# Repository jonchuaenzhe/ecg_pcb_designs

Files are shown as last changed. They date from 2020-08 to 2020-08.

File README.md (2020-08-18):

# EG3301R: Custom ECG Printed Circuit Board Designs

This repo contains the EAGLE files for the PCB design of a prototype double-lead ECG filter and amplifier as well as the final product: a compact 12-lead ECG filter and amplifier that has maximum dimensions of 70mm by 50mm. The pins S0 and S1 control the multiplexer that switches the input signal to the ECG monitor such that a ECG which comprises of 3 rows of 4 leads (plus 1 row of Lead 2) can be generated.

Picture of a Standard ECG

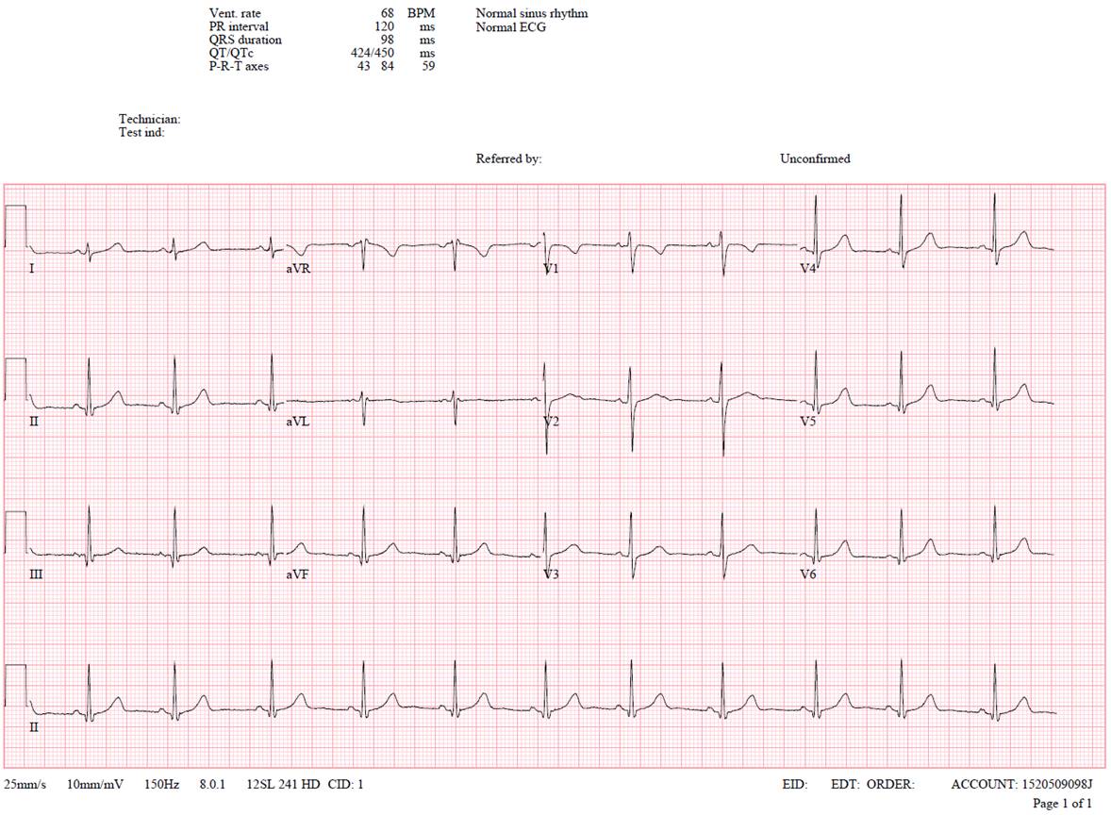
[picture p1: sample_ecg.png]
Picture of a Standard ECG


Board Design For 2-Lead ECG

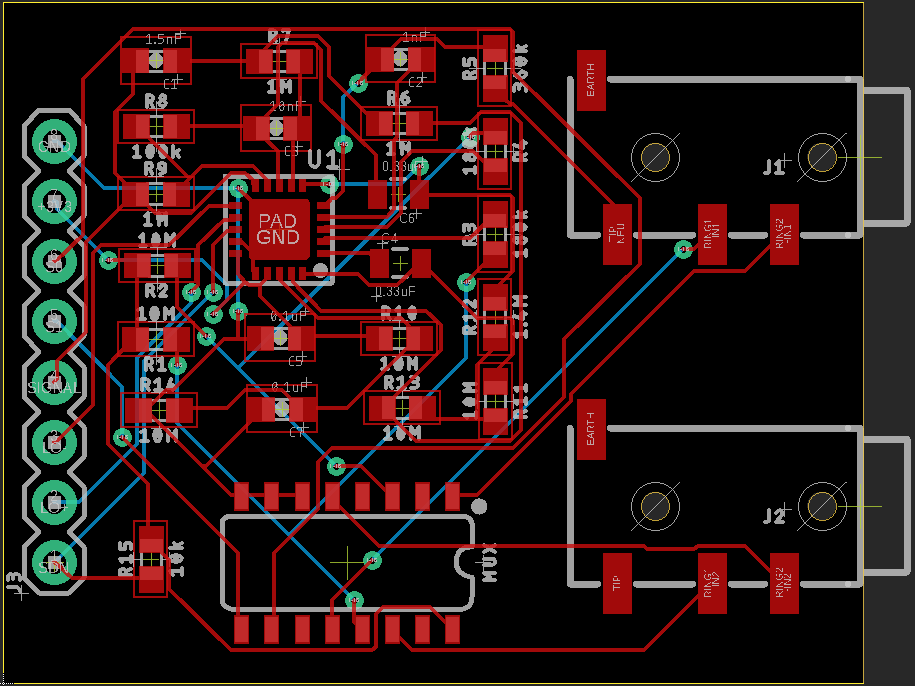
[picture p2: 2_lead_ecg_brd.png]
Board Design For 2-Lead ECG


Board Design For 12-Lead ECG

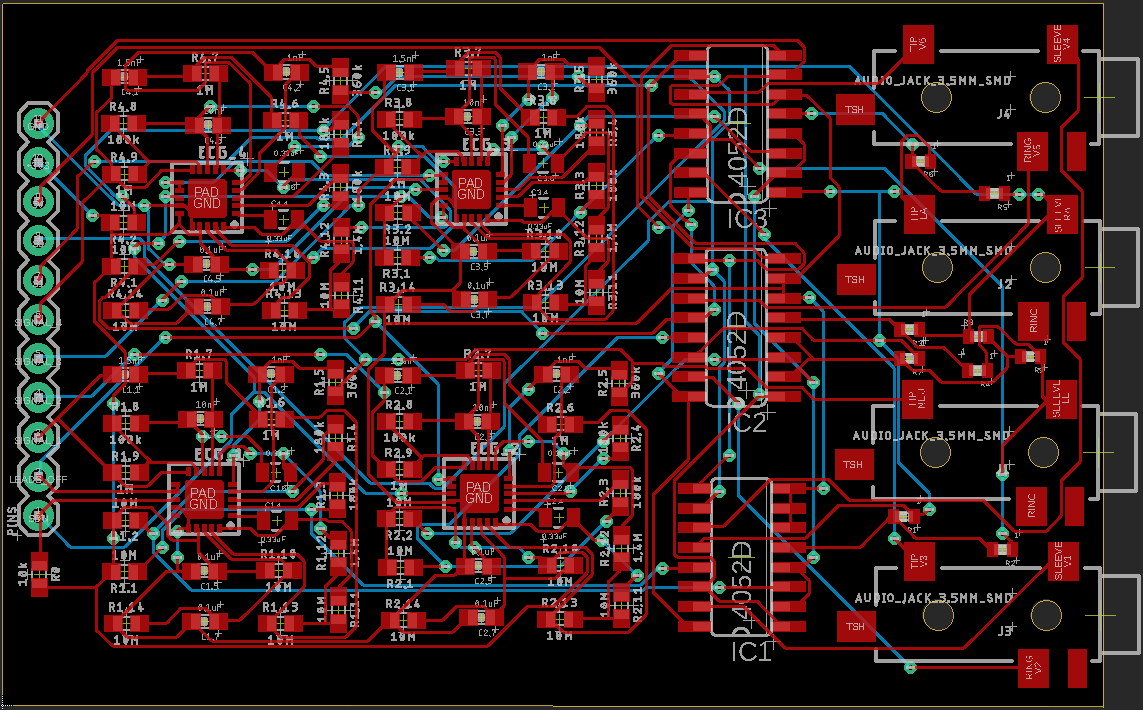
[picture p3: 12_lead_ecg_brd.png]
Board Design For 12-Lead ECG


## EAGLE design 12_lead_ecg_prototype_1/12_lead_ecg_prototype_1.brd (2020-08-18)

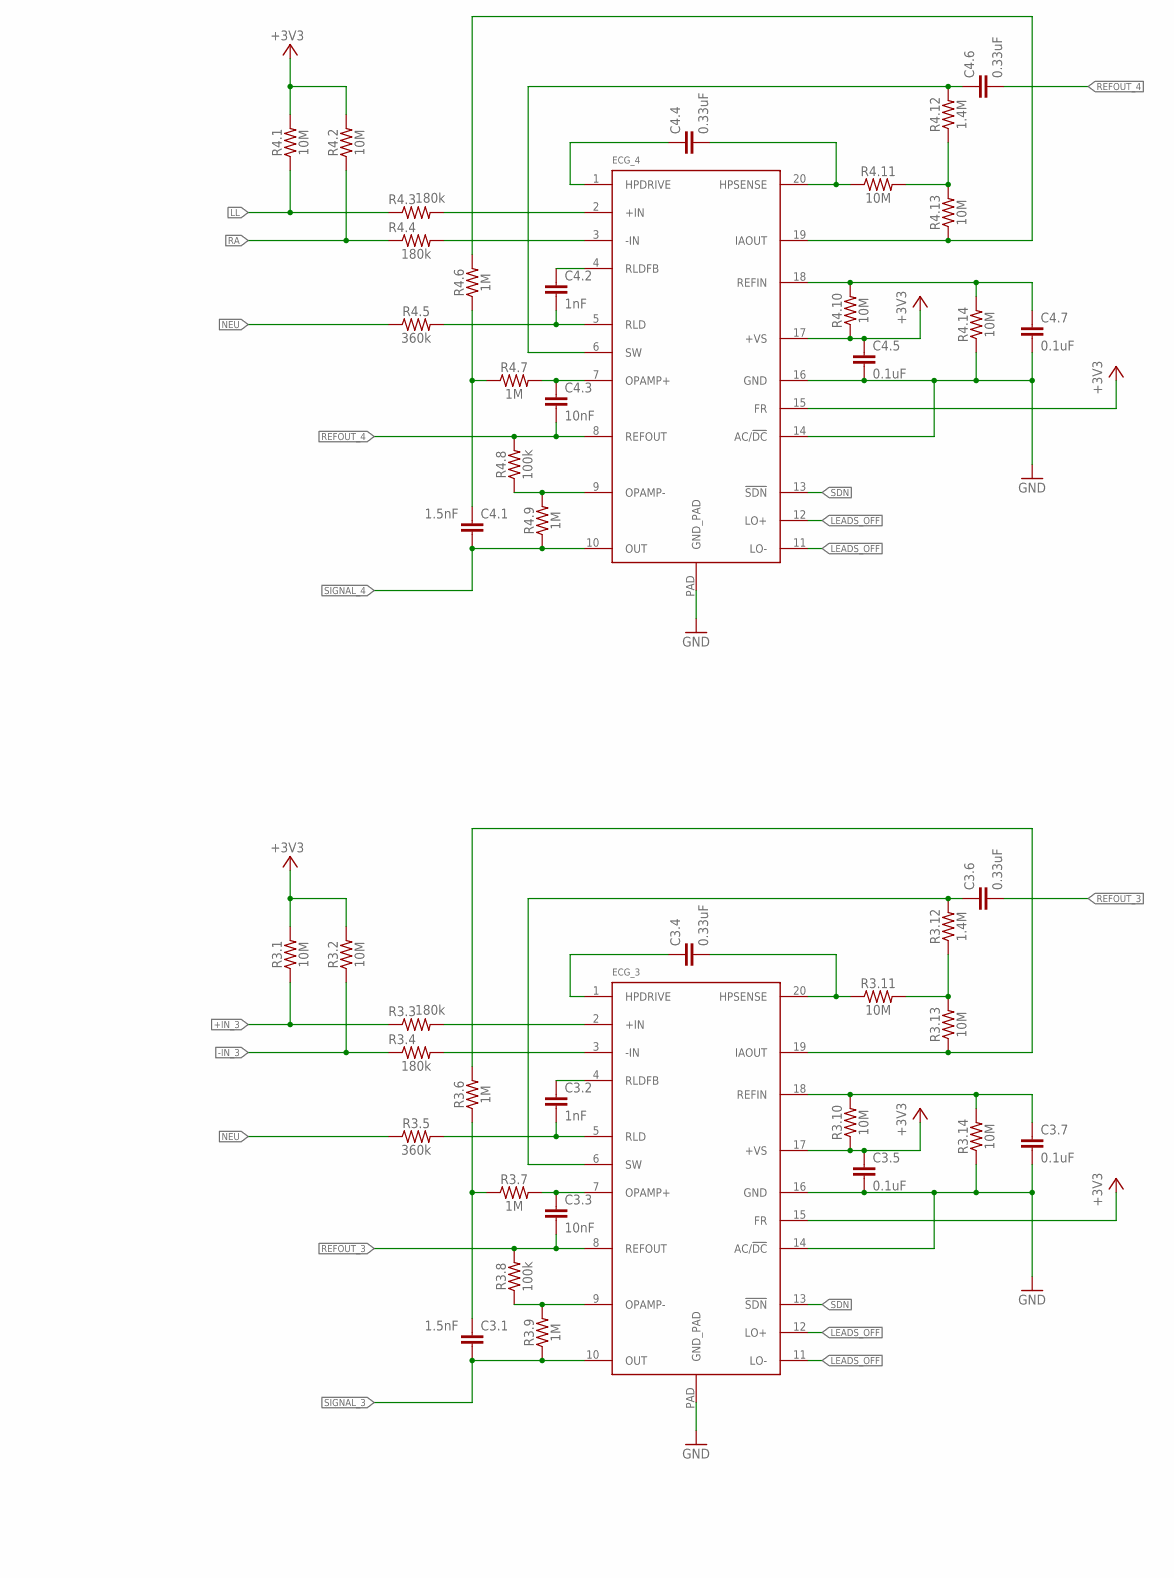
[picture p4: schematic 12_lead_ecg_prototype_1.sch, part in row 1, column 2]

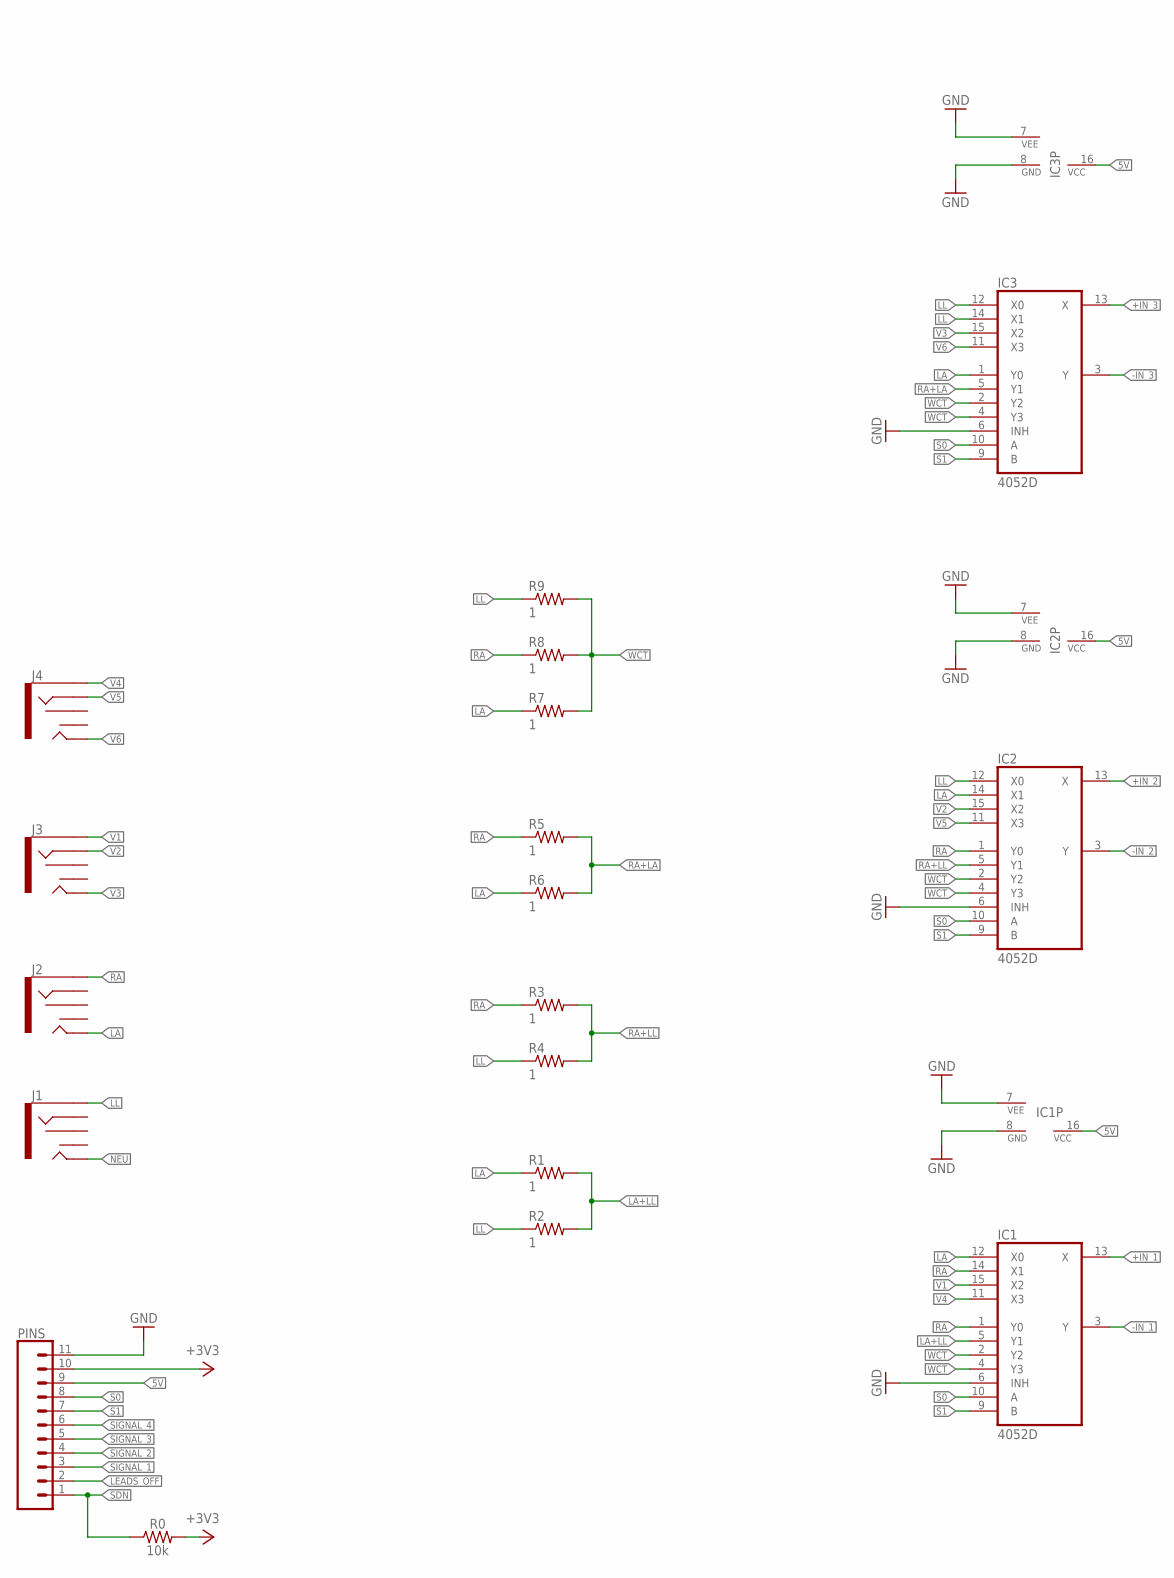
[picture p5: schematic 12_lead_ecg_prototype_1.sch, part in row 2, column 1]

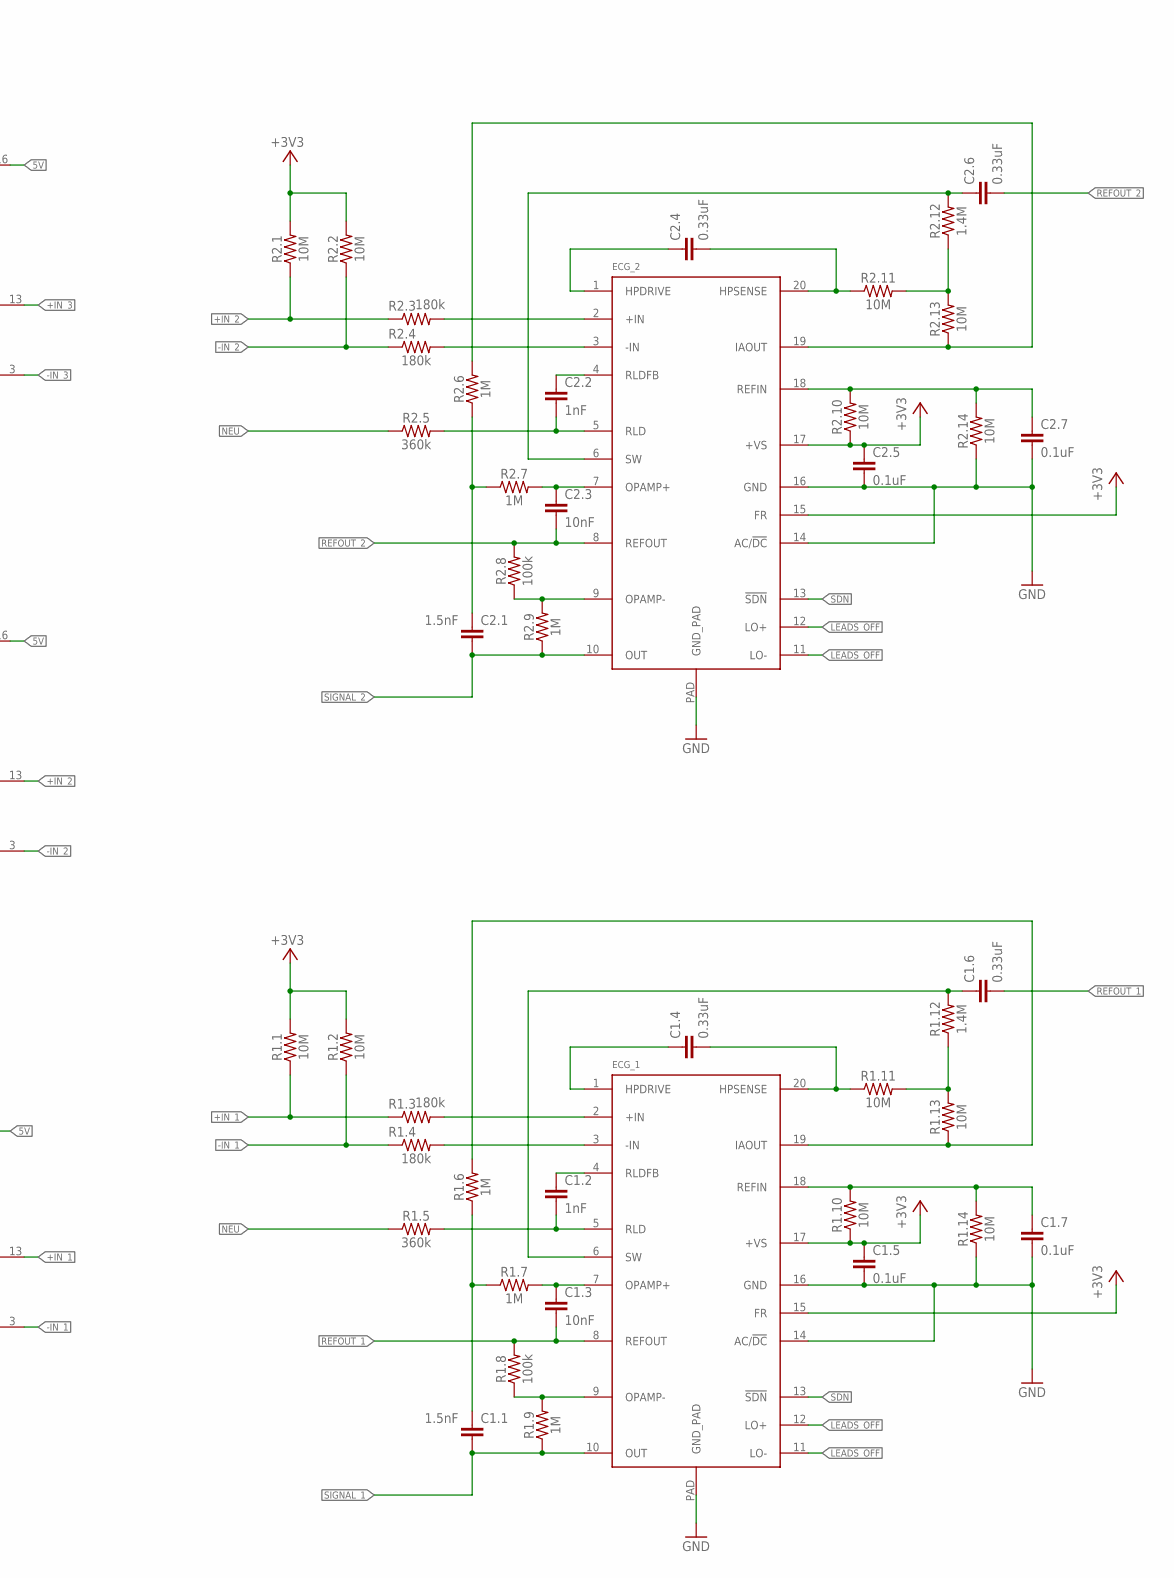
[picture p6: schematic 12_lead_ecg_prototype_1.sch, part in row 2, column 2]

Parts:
C1.1, C2.1, C3.1, C4.1: 1.5nF; 0603-CAP
C1.2, C2.2, C3.2, C4.2: 1nF; 0603-CAP
C1.3, C2.3, C3.3, C4.3: 10nF; 0603-CAP
C1.4, C1.6, C2.4, C2.6, C3.4, C3.6, C4.4, C4.6: 0.33uF; 0805
C1.5, C1.7, C2.5, C2.7, C3.5, C3.7, C4.5, C4.7: 0.1uF; 0603-CAP
ECG_1, ECG_2, ECG_3, ECG_4: AD8232ACPZ-R7; LFCSP_20
IC1, IC2, IC3: 4052D; SO16
J1, J2, J3, J4: AUDIO_JACK_3.5MM_SMD; AUDIO-JACK-3.5MM-SMD
PINS: CONN_11; 1X11
R0: 10k; 0603
R1, R2, R3, R4, R5, R6, R7, R8, R9: 1; 0402-RES
R1.1, R1.2, R1.10, R1.11, R1.13, R1.14, R2.1, R2.2, R2.10, R2.11, R2.13, R2.14, R3.1, R3.2, R3.10, R3.11, R3.13, R3.14, R4.1, R4.2, R4.10, R4.11, R4.13, R4.14: 10M; 0603
R1.3, R1.4, R2.3, R2.4, R3.3, R3.4, R4.3, R4.4: 180k; 0603
R1.5, R2.5, R3.5, R4.5: 360k; 0603
R1.6, R1.7, R1.9, R2.6, R2.7, R2.9, R3.6, R3.7, R3.9, R4.6, R4.7, R4.9: 1M; 0603
R1.8, R2.8, R3.8, R4.8: 100k; 0603
R1.12, R2.12, R3.12, R4.12: 1.4M; 0603

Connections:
5V: IC1.16 (VCC), IC2.16 (VCC), IC3.16 (VCC), PINS.9
+3V3: C1.5.1, C2.5.1, C3.5.1, C4.5.1, ECG_1.15 (FR), ECG_1.17 (+VS), ECG_2.15 (FR), ECG_2.17 (+VS), ECG_3.15 (FR), ECG_3.17 (+VS), ECG_4.15 (FR), ECG_4.17 (+VS), PINS.10, R0.2, R1.1.2, R1.2.2, R1.10.1, R2.1.2, R2.2.2, R2.10.1, R3.1.2, R3.2.2, R3.10.1, R4.1.2, R4.2.2, R4.10.1
+IN_1: IC1.13 (X), R1.1.1, R1.3.1
+IN_2: IC2.13 (X), R2.1.1, R2.3.1
+IN_3: IC3.13 (X), R3.1.1, R3.3.1
-IN_1: IC1.3 (Y), R1.2.1, R1.4.1
-IN_2: IC2.3 (Y), R2.2.1, R2.4.1
-IN_3: IC3.3 (Y), R3.2.1, R3.4.1
GND: C1.5.2, C1.7.2, C2.5.2, C2.7.2, C3.5.2, C3.7.2, C4.5.2, C4.7.2, ECG_1.14 (AC/!DC), ECG_1.16 (GND), ECG_1.PAD (GND_PAD), ECG_2.14 (AC/!DC), ECG_2.16 (GND), ECG_2.PAD (GND_PAD), ECG_3.14 (AC/!DC), ECG_3.16 (GND), ECG_3.PAD (GND_PAD), ECG_4.14 (AC/!DC), ECG_4.16 (GND), ECG_4.PAD (GND_PAD), IC1.6 (INH), IC1.7 (VEE), IC1.8 (GND), IC2.6 (INH), IC2.7 (VEE), IC3.6 (INH), IC3.7 (VEE), PINS.11, R1.14.1, R2.14.1, R3.14.1, R4.14.1
LA: IC1.12 (X0), IC2.14 (X1), IC3.1 (Y0), J2.TIP, R1.1, R6.1, R7.1
LA+LL: IC1.5 (Y1), R1.2, R2.2
LEADS_OFF: ECG_1.11 (LO-), ECG_1.12 (LO+), ECG_2.11 (LO-), ECG_2.12 (LO+), ECG_3.11 (LO-), ECG_3.12 (LO+), ECG_4.11 (LO-), ECG_4.12 (LO+), PINS.2
LL: IC2.12 (X0), IC3.12 (X0), IC3.14 (X1), J1.SLEEVE, R2.1, R4.1, R4.1.1, R4.3.1, R9.1
unnamed: ECG_1.9 (OPAMP-), R1.8.1, R1.9.2
unnamed: ECG_2.2 (+IN), R2.3.2
unnamed: ECG_1.2 (+IN), R1.3.2
unnamed: ECG_1.3 (-IN), R1.4.2
unnamed: ECG_2.3 (-IN), R2.4.2
unnamed: C1.1.1, R1.6.1, R1.7.1
unnamed: C1.3.1, ECG_1.7 (OPAMP+), R1.7.2
unnamed: C1.2.1, ECG_1.4 (RLDFB)
unnamed: C1.2.2, ECG_1.5 (RLD), R1.5.2
unnamed: ECG_1.19 (IAOUT), R1.6.2, R1.13.1
unnamed: C1.6.1, ECG_1.6 (SW), R1.12.2
unnamed: C1.7.1, ECG_1.18 (REFIN), R1.10.2, R1.14.2
unnamed: R1.11.2, R1.12.1, R1.13.2
unnamed: C1.4.2, ECG_1.20 (HPSENSE), R1.11.1
unnamed: C1.4.1, ECG_1.1 (HPDRIVE)
unnamed: C2.2.1, ECG_2.4 (RLDFB)
unnamed: C2.2.2, ECG_2.5 (RLD), R2.5.2
unnamed: IC2.8 (GND), IC3.8 (GND)
unnamed: C2.1.1, R2.6.1, R2.7.1
unnamed: C2.3.1, ECG_2.7 (OPAMP+), R2.7.2
unnamed: ECG_2.9 (OPAMP-), R2.8.1, R2.9.2
unnamed: ECG_2.19 (IAOUT), R2.6.2, R2.13.1
unnamed: C2.6.1, ECG_2.6 (SW), R2.12.2
unnamed: R2.11.2, R2.12.1, R2.13.2
unnamed: C2.4.2, ECG_2.20 (HPSENSE), R2.11.1
unnamed: C2.4.1, ECG_2.1 (HPDRIVE)
unnamed: C2.7.1, ECG_2.18 (REFIN), R2.10.2, R2.14.2
unnamed: ECG_3.2 (+IN), R3.3.2
unnamed: ECG_3.3 (-IN), R3.4.2
unnamed: C3.2.1, ECG_3.4 (RLDFB)
unnamed: C3.2.2, ECG_3.5 (RLD), R3.5.2
unnamed: C3.1.1, R3.6.1, R3.7.1
unnamed: C3.3.1, ECG_3.7 (OPAMP+), R3.7.2
unnamed: ECG_3.9 (OPAMP-), R3.8.1, R3.9.2
unnamed: ECG_3.19 (IAOUT), R3.6.2, R3.13.1
unnamed: C3.6.1, ECG_3.6 (SW), R3.12.2
unnamed: R3.11.2, R3.12.1, R3.13.2
unnamed: C3.4.2, ECG_3.20 (HPSENSE), R3.11.1
unnamed: C3.4.1, ECG_3.1 (HPDRIVE)
unnamed: C3.7.1, ECG_3.18 (REFIN), R3.10.2, R3.14.2
unnamed: ECG_4.2 (+IN), R4.3.2
unnamed: ECG_4.3 (-IN), R4.4.2
unnamed: C4.2.1, ECG_4.4 (RLDFB)
unnamed: C4.2.2, ECG_4.5 (RLD), R4.5.2
unnamed: C4.1.1, R4.6.1, R4.7.1
unnamed: C4.3.1, ECG_4.7 (OPAMP+), R4.7.2
unnamed: ECG_4.9 (OPAMP-), R4.8.1, R4.9.2
unnamed: ECG_4.19 (IAOUT), R4.6.2, R4.13.1
unnamed: C4.6.1, ECG_4.6 (SW), R4.12.2
unnamed: R4.11.2, R4.12.1, R4.13.2
unnamed: C4.4.2, ECG_4.20 (HPSENSE), R4.11.1
unnamed: C4.4.1, ECG_4.1 (HPDRIVE)
unnamed: C4.7.1, ECG_4.18 (REFIN), R4.10.2, R4.14.2
NEU: J1.TIP, R1.5.1, R2.5.1, R3.5.1, R4.5.1
RA: IC1.1 (Y0), IC1.14 (X1), IC2.1 (Y0), J2.SLEEVE, R3.1, R4.2.1, R4.4.1, R5.1, R8.1
RA+LA: IC3.5 (Y1), R5.2, R6.2
RA+LL: IC2.5 (Y1), R3.2, R4.2
REFOUT_1: C1.3.2, C1.6.2, ECG_1.8 (REFOUT), R1.8.2
REFOUT_2: C2.3.2, C2.6.2, ECG_2.8 (REFOUT), R2.8.2
REFOUT_3: C3.3.2, C3.6.2, ECG_3.8 (REFOUT), R3.8.2
REFOUT_4: C4.3.2, C4.6.2, ECG_4.8 (REFOUT), R4.8.2
S0: IC1.10 (A), IC2.10 (A), IC3.10 (A), PINS.8
S1: IC1.9 (B), IC2.9 (B), IC3.9 (B), PINS.7
SDN: ECG_1.13 (!SDN), ECG_2.13 (!SDN), ECG_3.13 (!SDN), ECG_4.13 (!SDN), PINS.1, R0.1
SIGNAL_1: C1.1.2, ECG_1.10 (OUT), PINS.3, R1.9.1
SIGNAL_2: C2.1.2, ECG_2.10 (OUT), PINS.4, R2.9.1
SIGNAL_3: C3.1.2, ECG_3.10 (OUT), PINS.5, R3.9.1
SIGNAL_4: C4.1.2, ECG_4.10 (OUT), PINS.6, R4.9.1
V1: IC1.15 (X2), J3.SLEEVE
V2: IC2.15 (X2), J3.RING
V3: IC3.15 (X2), J3.TIP
V4: IC1.11 (X3), J4.SLEEVE
V5: IC2.11 (X3), J4.RING
V6: IC3.11 (X3), J4.TIP
WCT: IC1.2 (Y2), IC1.4 (Y3), IC2.2 (Y2), IC2.4 (Y3), IC3.2 (Y2), IC3.4 (Y3), R7.2, R8.2, R9.2

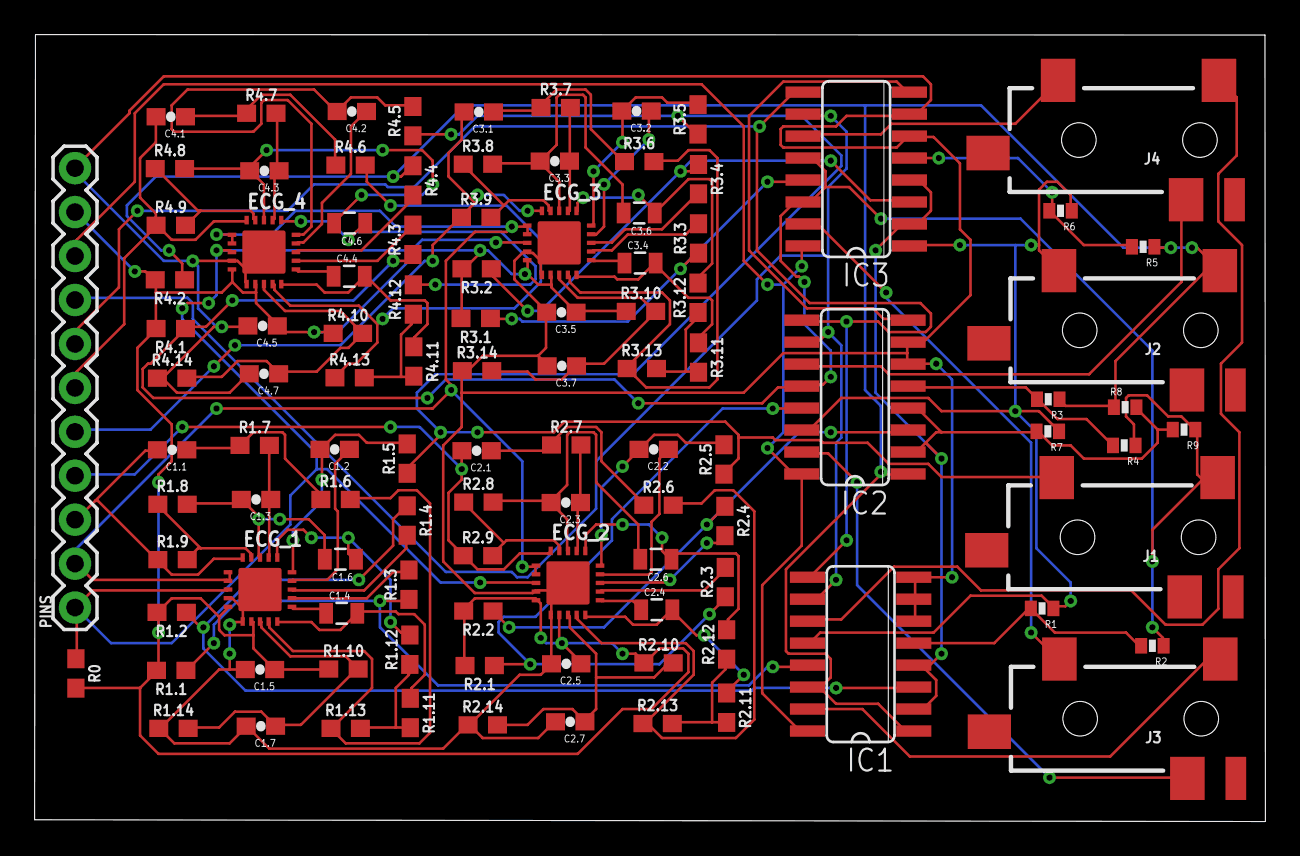
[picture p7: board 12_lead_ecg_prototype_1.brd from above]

Board: 2 copper layers, 71.2 x 45.5 mm, 106 parts (0 on the bottom side), 88 nets.

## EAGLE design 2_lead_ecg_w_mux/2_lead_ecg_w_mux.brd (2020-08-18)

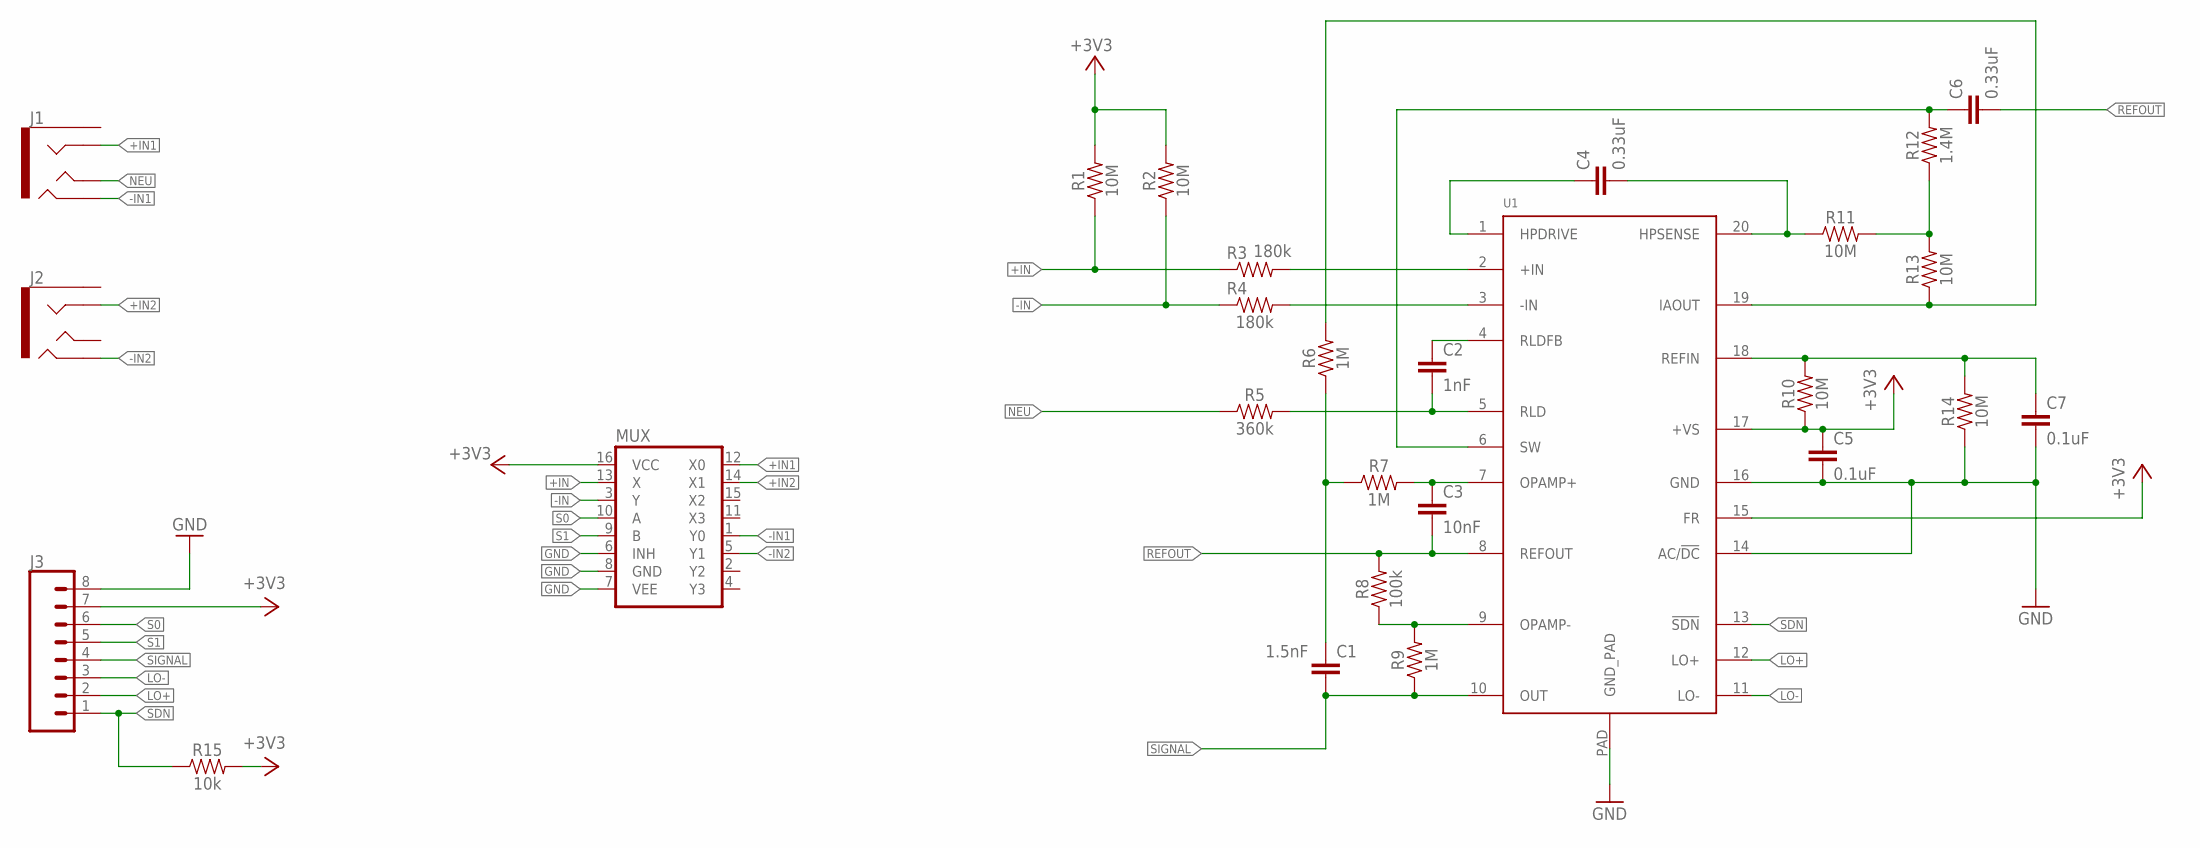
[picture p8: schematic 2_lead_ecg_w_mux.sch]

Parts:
C1: 1.5nF; 0603-CAP
C2: 1nF; 0603-CAP
C3: 10nF; 0603-CAP
C4, C6: 0.33uF; 0805
C5, C7: 0.1uF; 0603-CAP
J1, J2: AUDIO_JACK_TRRSSMD_RA; AUDIO_JACK_3.5MM_TRRS_SMD_RA
J3: CONN_08"; 1X08
MUX: 74HC4052D; SO16
R1, R2, R10, R11, R13, R14: 10M; 0603
R3, R4: 180k; 0603
R5: 360k; 0603
R6, R7, R9: 1M; 0603
R8: 100k; 0603
R12: 1.4M; 0603
R15: 10k; 0603
U1: AD8232ACPZ-R7; LFCSP_20

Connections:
+3V3: C5.1, J3.7, MUX.16 (VCC), R1.2, R2.2, R10.1, R15.2, U1.15 (FR), U1.17 (+VS)
+IN: MUX.13 (X), R1.1, R3.1
+IN1: J1.RING1, MUX.12 (X0)
+IN2: J2.RING1, MUX.14 (X1)
-IN: MUX.3 (Y), R2.1, R4.1
-IN1: J1.RING2, MUX.1 (Y0)
-IN2: J2.RING2, MUX.5 (Y1)
GND: C5.2, C7.2, J3.8, MUX.6 (INH), MUX.7 (VEE), MUX.8 (GND), R14.1, U1.14 (AC/!DC), U1.16 (GND), U1.PAD (GND_PAD)
LO+: J3.2, U1.12 (LO+)
LO-: J3.3, U1.11 (LO-)
unnamed: R8.1, R9.2, U1.9 (OPAMP-)
unnamed: R3.2, U1.2 (+IN)
unnamed: R4.2, U1.3 (-IN)
unnamed: C1.1, R6.1, R7.1
unnamed: C3.1, R7.2, U1.7 (OPAMP+)
unnamed: C2.1, U1.4 (RLDFB)
unnamed: C2.2, R5.2, U1.5 (RLD)
unnamed: R6.2, R13.1, U1.19 (IAOUT)
unnamed: C6.1, R12.2, U1.6 (SW)
unnamed: C7.1, R10.2, R14.2, U1.18 (REFIN)
unnamed: R11.2, R12.1, R13.2
unnamed: C4.2, R11.1, U1.20 (HPSENSE)
unnamed: C4.1, U1.1 (HPDRIVE)
NEU: J1.TIP, R5.1
REFOUT: C3.2, C6.2, R8.2, U1.8 (REFOUT)
S0: J3.6, MUX.10 (A)
S1: J3.5, MUX.9 (B)
SDN: J3.1, R15.1, U1.13 (!SDN)
SIGNAL: C1.2, J3.4, R9.1, U1.10 (OUT)

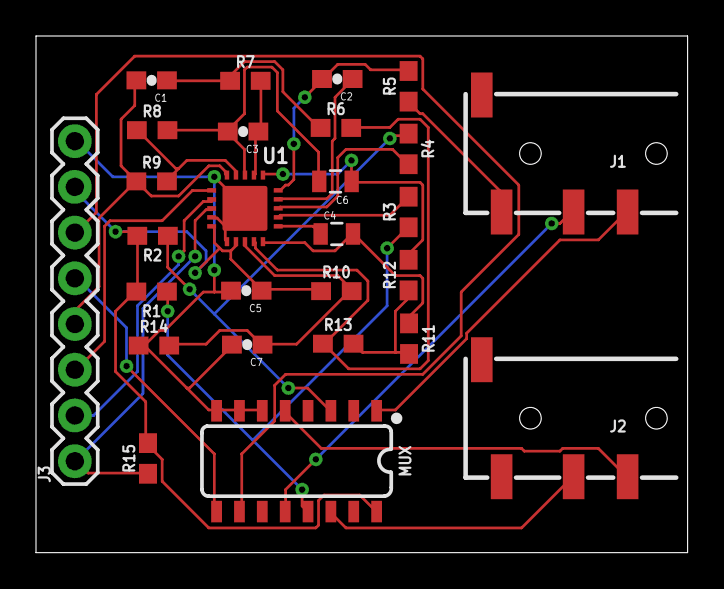
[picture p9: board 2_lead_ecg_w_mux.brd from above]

Board: 2 copper layers, 36.2 x 28.7 mm, 27 parts (0 on the bottom side), 29 nets.

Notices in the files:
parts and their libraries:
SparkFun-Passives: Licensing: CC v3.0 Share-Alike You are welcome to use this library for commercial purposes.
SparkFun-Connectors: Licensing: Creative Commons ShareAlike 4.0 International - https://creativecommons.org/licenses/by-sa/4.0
